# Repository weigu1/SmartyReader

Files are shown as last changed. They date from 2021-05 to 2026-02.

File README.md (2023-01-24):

# SmartyReader: Reading encrypted Luxembourgish smartmeter data

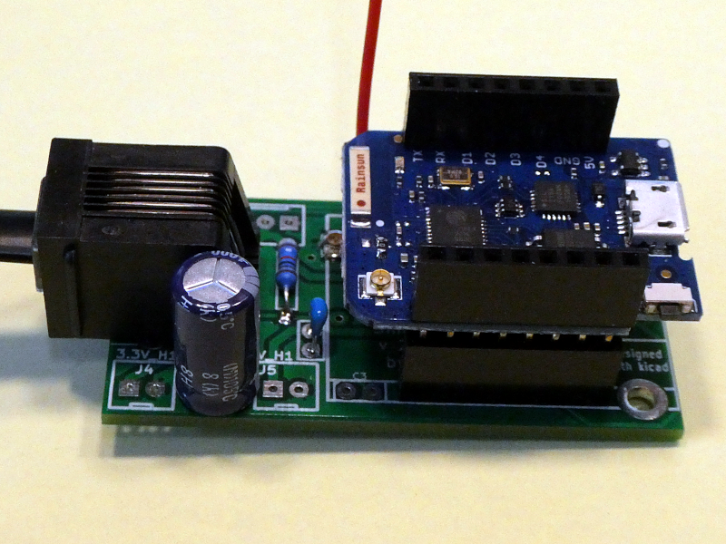
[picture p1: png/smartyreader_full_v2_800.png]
smartyreader


## All infos on: <http://weigu.lu/microcontroller/smartyReader/index.html>

## Some infos

Because of the EU Energy Efficiency Directive from 2012 the gas and electricity Distribution System Operators (DSO) in Luxembourg replaced there gas and energy meters with smartmeters (named smarty :() from Sagemcom (T210-D).

As it seems the same smartmeters are deployed in Sweden, parts of Austria and the Netherlands.

These smartmeters have a user port that delivers 10 second data (RJ12 connector under the green lid). The P1 data output communication protocol and format is specified in the  [Dutch Smart Meter Requirements v5.0.2 ](https://smarty.creos.net/wp-content/uploads/DutchSmartMeterRequirements.pdf). The solution deployed in Luxembourg includes an additional security layer standard that is conform to the IDIS package 2.0 requirement. The encryption layer is based on DLMS security suite 0 algorithm: AES128-GCM. More information can be found in this [document](https://smarty.creos.net/wp-content/uploads/P1PortSpecification.pdf).

The Smartyreader is a simple board designed with KiCAD and decrypting the smartmeter data with an ESP8266 (Lolin D1 mini pro). The data is then published over MQTT via WiFi or Ethernet. A new version allows also to use LoRa or LoRaWAN.

For infos from the newest software look here: <https://github.com/weigu1/SmartyReader/tree/main/Arduino/SmartyReader_P1_WiFi_Ethernet>.

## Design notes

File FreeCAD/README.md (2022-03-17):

# SmartyReader housing

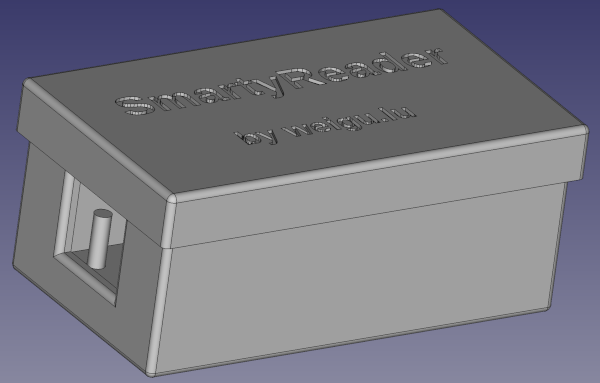
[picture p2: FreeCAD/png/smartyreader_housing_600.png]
smartyreader


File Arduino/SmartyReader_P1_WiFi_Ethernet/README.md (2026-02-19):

# SmartyReader: Reading encrypted Luxembourgish smartmeter data

## The Software (MQTT via WiFi or Ethernet) to use with an ESP8266

### Install Arduino and the libraries needed:

+ Good to know:<br>
1. To program the D1 mini pro, remove it from the socket!
2. If you buy today D1 mini pro's you get often cloned boards. Select in Arduino IDE D1 mini (clone)!
3. The Ethernet version needs a RESET (button) after being connected to the Smartmeter to start.

The newer software uses my ESPToolbox lib, that is included in the sketch folder.

First install the newest Arduino IDE. To use our ESP8266 LOLIN/WEMOS we add this line ```http://arduino.esp8266.com/stable/package_esp8266com_index.json``` to ```File-Preferences-Additional_Boards_Manager_URLs:```.

Then we install support for ESP8266 boards by going to `Tools > Board: > Boards Manager...`. In the Manager window we type **esp8266** in the search field, select esp8266 and click on `install`. Close the window and choose the board `LOLIN/WEMOS D1 mini Pro` under `Tools > Board:` (you have to scroll).

We need a the following libraries:

+ `Crypto` (Rhys Wheatherley)
+ `PubSubClient`  (by Nick O'Leary)
+ `ArduinoJson` (Benoit Blanchon)
+ `circular Buffer` (AgileWare, Roberto Lo Giacco)
+ `BME280` (Tyler Glenn); only if you use a BME280! 

To install them go to `Tools > Manage Libraries...`. Type in the search field the name of the library, choose it and install it. Sometimes you have to scroll down to find the right lib.

If you want to use the config `config.h` file uncomment `SECRETS`. If you want to use the a secret config file, create a folder named `Secrets` in the sketchbook libraries folder (`sketchbook/libraries`). Now copy the content of `config.h` to a file named `secrets.h`. Place this file in the `Secrets` folder.

### Version 1.7

Since january first 2025 the costs for the electricity net in Luxembourg include, in addition to the fixed costs, a new calculation that takes power classes into account (3&#8239;kW, 7&#8239;kW, 12&#8239;kW ...). You are assigned to such a power class and have to pay more if your consumption exceeds it.

The new software version calculates this data if required. In addition, thanks to Markus Schoellauf, an MQTT discovery method for Home Assistant has been integrated. We also now have a last will :) thanks to Jean-Marie Quintus.

These two changes have not yet been thoroughly tested. If you find an error, please let me know.

### Version 1.6

This new version got a lot of changes:

A new config file (`config.h`) contains all the things that must be changed or are safe to change.

In this new version I changed the publishing format. Every item (DSMR and new calculated values) is published under its own topic. No more JSON strings but directly the values (easier to handle wit home automation software). In `config.h` (or secrets.h) you can decide with 'y/n' if you want to publish the parameter or not.

To be better able to write simpler rules I added calculated values described below.

#### Define lines in the main program

The main program (.ino) contains still the define lines that can be commented or uncommented. Removing the two slashes (`//`) means the line is active (uncommented). To make a line inactive, add two slashes at the beginning of the line. 

+ `USE_SECRETS` will use a file named `secrets.h` instead of the `config.h` file. This file must contain the same things than the config file (`config.h`) but must be located in the sketchbook `libraries` folder of your Arduino IDE  in a folder named `Secrets`. This makes it easier to test and distribute the software without sharing the WiFi password and so compromising security.

+ `OTA` will enable the Over The Air update possibility (security risk!). This comes handy to reprogram your SmartyReader while connected to the Smartmeter. In the config file you can change the name you see in the port menu of the Arduino IDE, and the password. To use a minimum of security we calculate an MD5 hash of our password, so that the password is not contained in cleartext in the Flash of the microcontroller. You can calculate MD5 hashes from a password with online tools.

+ `MQTTPASSWORD` enables an MQTT connection protected with a password (recommended!!). Check the config file to set the password.

+ `STATIC` can be used if you want a static IP instead of a changing IP. The IP address is set in the config file.

+ `ETHERNET` if you don't want to use WiFi. For this you must add a Funduino (W5100) breakout board to your SmartyReader.

+ `BME280_I2C` to add a temperature sensor to your SmartyReader. The data is published under the topics "bme280_temperature_C", "bme280_humidity_%" and "bme280_pressure_hPa". Don't forget to solder two 1.8k resistors (0805, R5 and R6) to your board! 

+ `GET_NTP_TIME` to add the the real time (from an NTP Server).

+ `PUBLISH_COOKED` is used to get only one JSON string with all the calculated values. In this new version every item (DSMR and calculated) is published under its own topic. No more JSON strings but directly the values (easier to handle wit home automation software). In `config.h` (or secrets.h) you can decide with 'y/n' if you want to publish the parameter or not.

+ `OLD_HARDWARE` must be used for boards before V2.0, because here the serial signal is inverted with hardware (transistor) instead of software.

+ `FUNDUINO_W5100` for Ethernet boards before V2.2 if using Ethernet.

#### The config file (`config.h`). 

Mandatory things to change are your WiFi credentials, your Smartmeter key (get it from your electricity distribution system operator) and the IP address of your MQTT server (e.g. Raspberry Pi).

The following things can be changed:

+ `PUBLISH_TIME`: in ms. The minimum is 10 seconds and it makes sense to use a multiple of this. A good value is 60000, to get data once a minute.

+ `SAMPLE_TIME_MIN`: The mean value of the power and the min and max values are calculated over this time. If we set this time to 10 min, 60 values are used to calculate the mean power.

+ `MQTT`: The client ID must be unique, so change it if you use more than one SmartyReader!! Choose your own topic. User and Password is only needed if you uncommented `MQTTPASSWORD`. Default port is 1883.

+ `WiFi`: With an MDNS name you can access your SmartyReader with the name .local instead the IP. With a hostname it is easier to find your SmartyReader IP with the router or nmap. If you use UDP to debug (look below) you can change here the IP address of your client and the port. You can also change the NTP server and your time zone.

+ `OTA`: If you use OTA (uncomment `OTA` in the main file (.ino)). 

+ `STATIC`: If you use a static IP address (uncomment `STATIC` in the main file (.ino)). 

+ `ETHERNET`: If you use an ethernet breakout board (uncomment `ETHERNET` in the main file (.ino)) you can change the MAC to get a unique address.

+ `AUTH_DATA`: In Austria this data is not hard coded, so here you can change it (17 byte!).

+ `PUBLISH`: In the two following tables you can define if a parameter is published or not. To prevent publishing, repalce the lowercase 'y' with another char e.g. 'n'.

#### Debugging

Debugging options are enabled in the main file (.ino) in the `setup()` function. By default all 3 logging options are enabled (true). 

+ `Tb.set_led_log(true)` uses the built-in LED for debugging (different blink patterns).
+ `Tb.set_serial_log(true,1)` uses the second (1 = Serial1) or third (ESP32, (2 = Serial2)) hardware serial interface to debug. The first (Serial or Serial0) is used by the Smartmeter and can't be used to debug. You can connect a Serial to USB adapter to this hardware interface pins (D4 (Tx1) and GND for ESP8266) and use a terminal program to log the stream.

+ `Tb.set_udp_log(true, UDP_LOG_PC_IP, UDP_LOG_PORT)` is the coolest option. Use a computer to get the logging over an UDP stream. On a Linux system (e.g. Raspberry Pi) you can use the `netcat` command (nc) in a terminal: `nc -kulw 0 6666`. The port and IP address are set in `config.h` under "WiFi and network settings".

To add your own debug strings use `Tb.log("mytext")`or `Tb.log_ln("mytext")`.

#### The calculated values

##### The smartmeter is a balancing counter

Smartmeter are balancing counter (german: saldierender Zähler). This can lead to confusion when looking at the power values from your Smartmeter.

###### A little example:

If your solar plant is giving you 6&#8239;kW on 3 phases (L1, L2, L3), you get 2&#8239;kW per phase. If you are charging your EV at the same time with 4&#8239;kW on phase L1, the SmartyReader will show you the following values:

`act_pwr_imported_p_plus` (1.7.0) = 2&#8239;kW

`act_pwr_exported_p_minus` (2.7.0) = 4&#8239;kW

`act_pwr_imp_p_plus_l1` (21.7.0) = 2&#8239;kW

`act_pwr_imp_p_plus_l2` (41.7.0) = 0&#8239;kW

`act_pwr_imp_p_plus_l3` (61.7.0) = 0&#8239;kW

`act_pwr_exp_p_minus_l1` (22.7.0) = 0&#8239;kW

`act_pwr_exp_p_minus_l2` (42.7.0) = 2&#8239;kW

`act_pwr_exp_p_minus_l3` (62.7.0) = 2&#8239;kW

But if we calculate the power from the energy values we see that in fact there is no energy imported and 2&#8239;kW are exported.

To calculate the power from energy we need two energy values (E1 and E2) and the time between these two values (&#916;t): P = (E2-E1)/&#916;t.

Another solution is to calculate the difference between `act_pwr_imported_p_plus` (1.7.0) and `act_pwr_exported_p_minus` (2.7.0). 
P = power exported - power imported. If this difference is positive we get an excess of solar power, and energy is only exported (no energy is imported). If it is negative (contrained to zero in software), we consume energy.

###### SmartyReader calculated values

To get a better overview, the new software is calculating the solar excess power, and the power from energy.

It calculates also the mean power over the last x minutes (x changeable in `config.h`), as the min and max values over the last x minutes. For this all available values (10 second values) are used. With these values it is easier to write rules for days with fast changing solar radiation.

## More infos on: <http://weigu.lu/microcontroller/smartyReader/index.html>

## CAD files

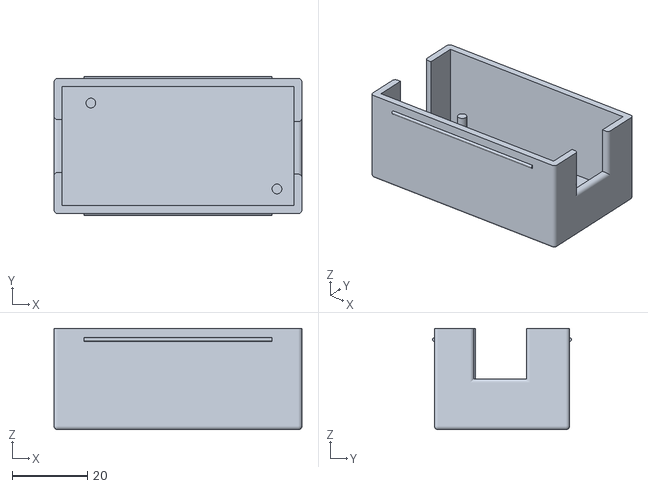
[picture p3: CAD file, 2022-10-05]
FreeCAD/SmartyReader_P1_WiFi-Case.stl
66.0 x 37.0 x 27.0

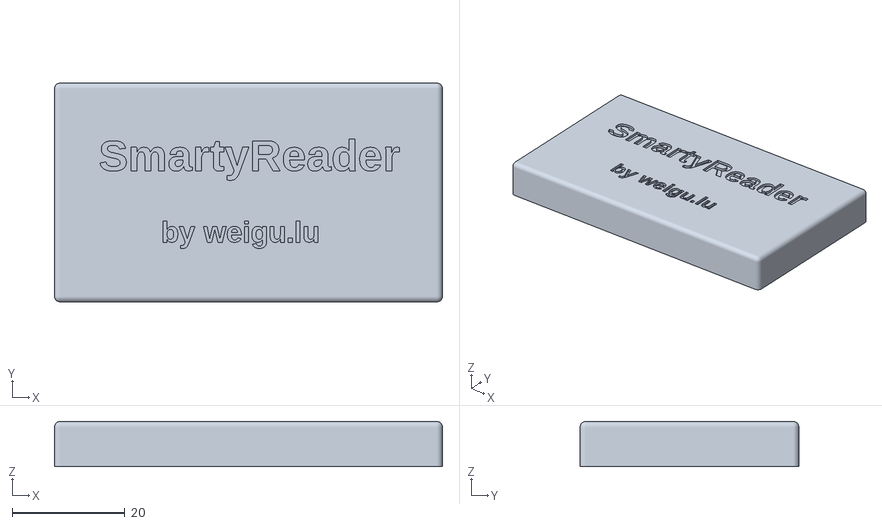
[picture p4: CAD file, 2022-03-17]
FreeCAD/SmartyReader_P1_WiFi_Lid.stl
68.8 x 38.8 x 8.00

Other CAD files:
FreeCAD/SmartyReader_P1_WiFi.FCStd

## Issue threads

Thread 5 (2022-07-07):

ESP32-POE-ISO sends mqtt messages in uneven time intervals

u20p17, 2022-07-07:
Hi,
I am using a ESP32-POE-ISO which get powered by POE and is located near the smartmeter (Sagemcom T210-D-r). I already got the encryption key and modified your 1.6 beta code in order that the ethernet was working (and the general MQTT/network... settings in the config file.
After flashing an connecting I get some data via MQTT. As a test I set the publish time to 10s. As you can see it is working like expected and suddenly it stops for several minutes (more than 70min!) and after that it is working again for some mqtt messages and then it stops again for a long time.

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

What could be the problem?

Furthermore, lot of the channels are just 0. Is this a problem of my smartmeter ( maybe the energy company has to activate them?) or might it be related to the code?

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

Here my updated code:
[SmartyReader_v1_6_beta.zip](https://github.com/weigu1/SmartyReader/files/9060960/SmartyReader_v1_6_beta.zip)

Thanks in advance!

weigu1, 2022-07-08:
Hi there,

First the simple question :) The zeros are related  to your energy company. In Luxembourg they sent in the beginning 700 bytes with the currents per phase, then after an update only 500 bytes without the currents. After some clients complained they now sent also the power per phase (1100 byte). So ask your company for more data.

I had the same problems in the beginning of the year with ESP32. They worked sometimes one week without complaint and then stopped for some hours without logging errors. I had no time to dig deeper and replaced them with ESP8266. We also had other problems with ESP32 that could be solved by downgrading on a core version before 3.0. So perhaps you could try this (in Boards manager you can choose the version).
Another problem could be a not enough or stable power supply (add a big capacitor).

Sorry, but for the moment I can't look into this more deeply.

Greetings
Guy

u20p17, 2022-07-13:
Hi,
Thanks for the answer. I will contact the energy company and ask if they can also activate the full data output of the smartmeter.

Do you have a complete set that you could sell me? Would save me some work for soldering the platine ;)

Thanks!

weigu1, 2022-07-14:
Hi,
For a kit, please send me your address to weigu@weigu.lu.
Greetings

Closed 2022-07-16.

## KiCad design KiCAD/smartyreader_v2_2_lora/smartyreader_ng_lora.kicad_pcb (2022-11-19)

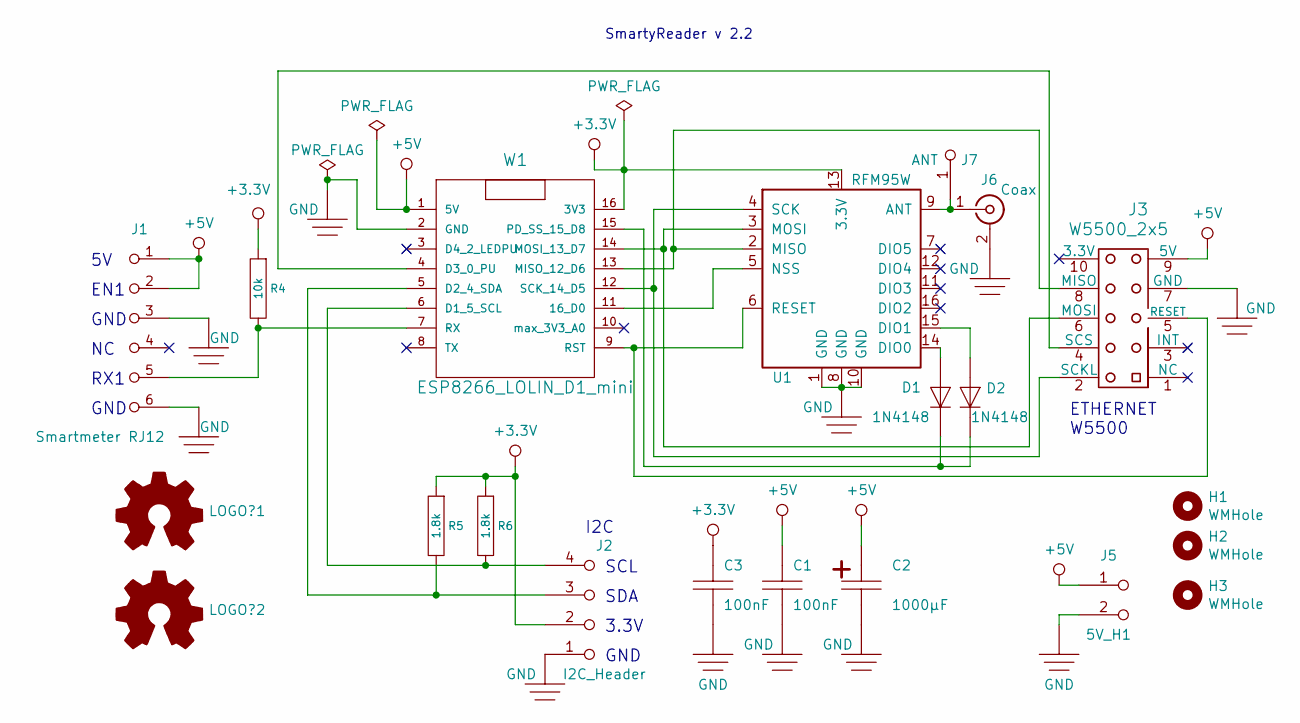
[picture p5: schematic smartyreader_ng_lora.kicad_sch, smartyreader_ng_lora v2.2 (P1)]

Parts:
C1, C3: 100nF; WC1
C2: 1000µF; WC1V
D1, D2: 1N4148; W0805
H1, H2, H3: WMHole; WPin_3mm
J1: Smartmeter RJ12; WRJ12
J2: I2C_Header; WSIL4_SL
J3: W5500_2x5; WW5500
J5: 5V_H1; WSIL2_SL
J6: Coax; U.FL_Molex_MCRF_73412-0110_Vertical
J7: ANT; WPin_1mm
LOGO?1, LOGO?2: Open_Hardware_Logo; OSHW-Logo_5.7x6mm_SilkScreen
R4: 10k; WR4
R5, R6: 1.8k; W0805
U1: RFM95W; HOPERF_RFM9XW_SMD
W1: ESP8266_LOLIN_D1_mini; WWEMOSD1

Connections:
+3.3V: C3.1, J2.2 (12), R4.1, R5.1, R6.1, U1.13 (3.3V), W1.16 (3V3)
+5V: C1.1, C2.1, J1.1, J1.2, J3.9 (5V), J5.1 (11), W1.1 (5V)
unnamed: D1.1 (A), U1.14 (DIO0)
unnamed: D1.2 (K), D2.2 (K), W1.15 (PD_SS_15_D8)
unnamed: D2.1 (A), U1.15 (DIO1)
unnamed: J1.5, R4.2, W1.7 (RX)
unnamed: J2.3 (13), R5.2, W1.5 (D2_4_SDA)
unnamed: J2.4 (14), R6.2, W1.6 (D1_5_SCL)
unnamed: J3.2 (SCKL), U1.4 (SCK), W1.12 (SCK_14_D5)
unnamed: J3.4 (SCS), W1.4 (D3_0_PU)
unnamed: J3.5 (RESET), U1.6 (RESET), W1.9 (RST)
unnamed: J3.6 (MOSI), U1.3 (MOSI), W1.14 (MOSI_13_D7)
unnamed: J3.8 (MISO), U1.2 (MISO), W1.13 (MISO_12_D6)
unnamed: J6.1 (In), J7.1 (11), U1.9 (ANT)
unnamed: U1.5 (NSS), W1.11 (16_D0)
~: C1.2, C2.2, C3.2, J1.3, J1.6, J2.1 (11), J3.7 (GND), J5.2 (12), J6.2 (Ext), U1.1 (GND), U1.8 (GND), U1.10 (GND), W1.2 (GND)

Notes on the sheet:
EN1
SCL
GND
SDA
SmartyReader v 2.2
ETHERNET W5500
3.3V
I2C
RX1

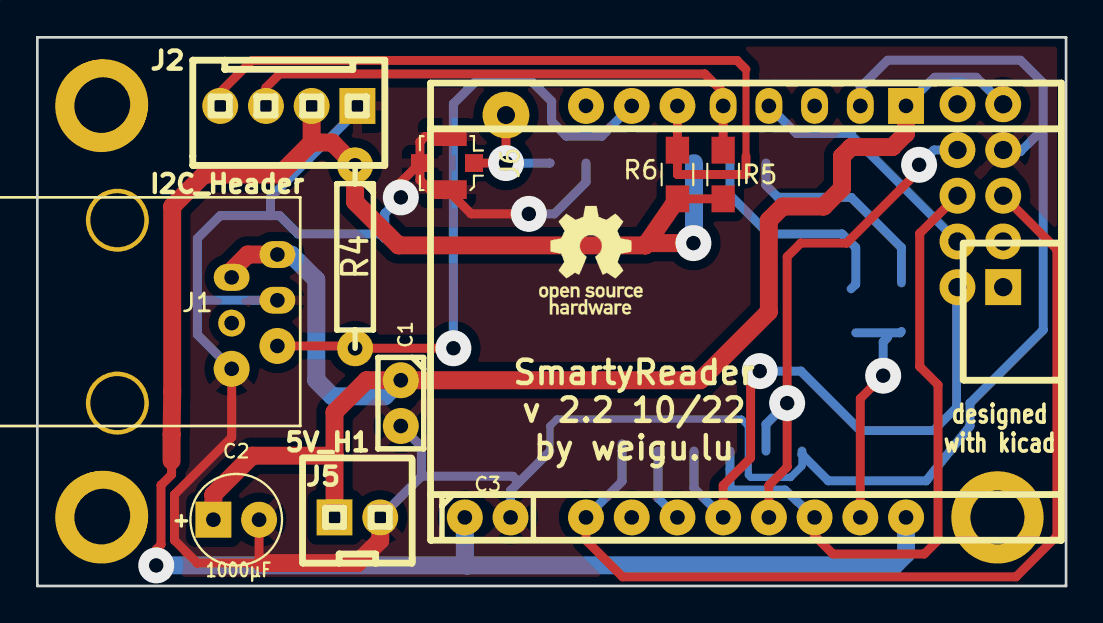
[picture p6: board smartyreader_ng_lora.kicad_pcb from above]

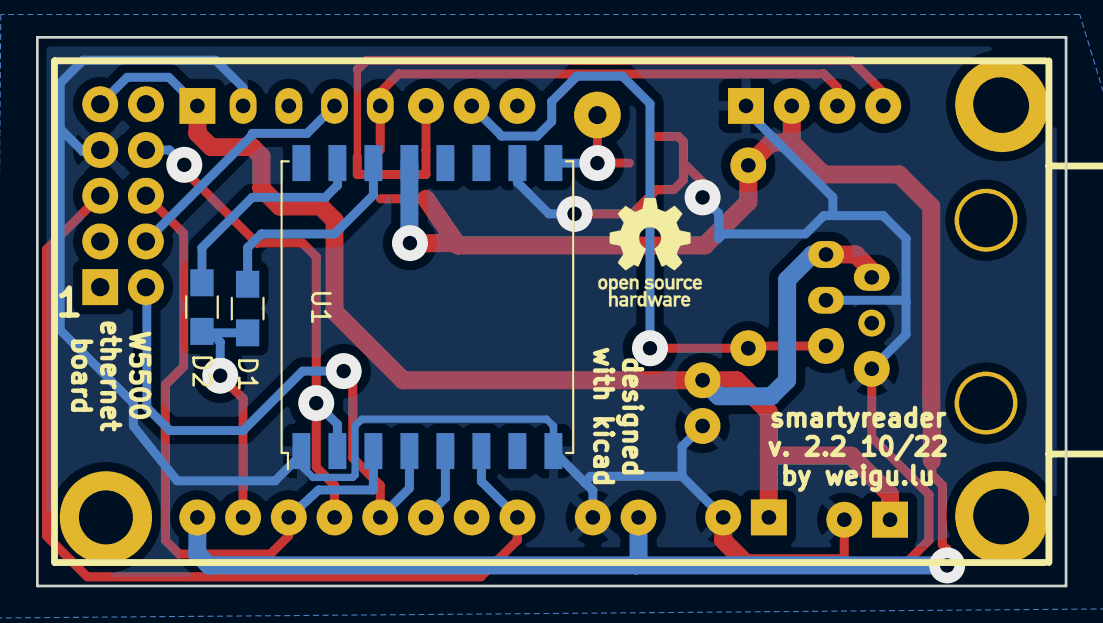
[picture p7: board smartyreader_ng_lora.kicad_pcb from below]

Board: 2 copper layers, 57.1 x 30.5 mm, 21 parts (5 on the bottom side), 16 nets.

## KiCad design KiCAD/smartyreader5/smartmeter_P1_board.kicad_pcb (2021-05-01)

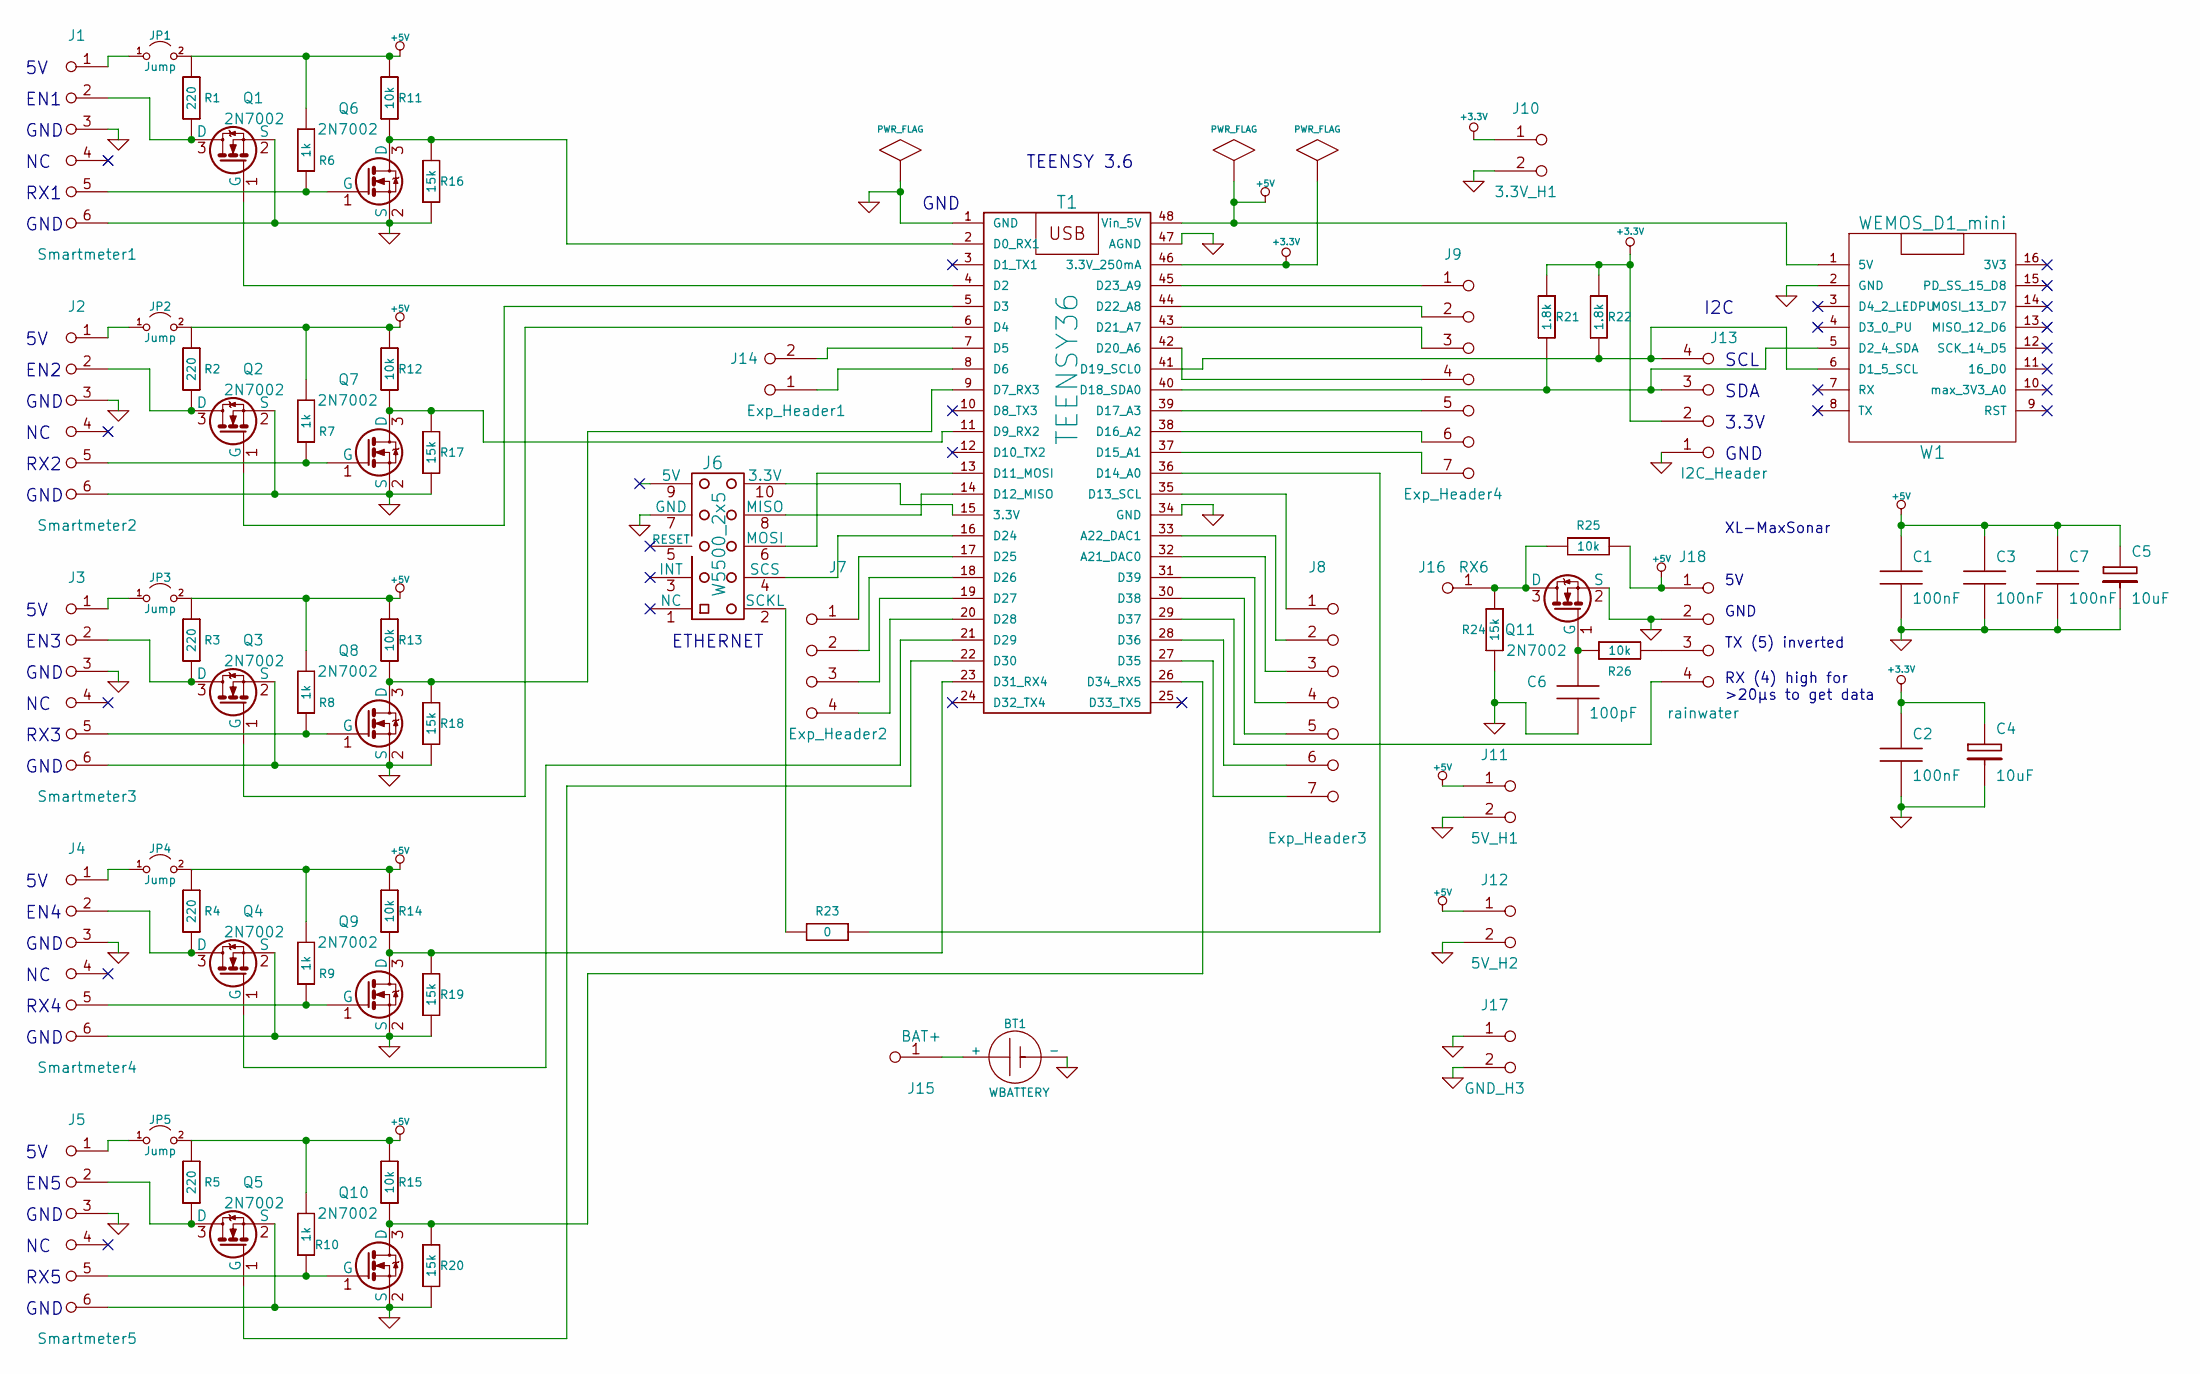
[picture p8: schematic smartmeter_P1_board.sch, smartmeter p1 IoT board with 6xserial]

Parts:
BT1: WBATTERY; WBAT
C1, C2, C3, C7: 100nF; W0805
C4, C5: 10uF; W1206
C6: 100pF; W0805
J1: Smartmeter1; WRJ12
J2: Smartmeter2; WRJ12
J3: Smartmeter3; WRJ12
J4: Smartmeter4; WRJ12
J5: Smartmeter5; WRJ12
J6: W5500_2x5; WW5500
J7: Exp_Header2; WSIL4_SL
J8: Exp_Header3; WSIL8_SL
J9: Exp_Header4; WSIL7_SL
J10: 3.3V_H1; WSIL2_SL
J11: 5V_H1; WSIL2_SL
J12: 5V_H2; WSIL2_SL
J13: I2C_Header; WSIL4_SL
J14: Exp_Header1; WSIL2_SL
J15: BAT+; WSIL1
J16: RX6; WSIL1
J17: GND_H3; WSIL2
J18: rainwater; WSIL4
JP1, JP2, JP3, JP4, JP5: Jump; WSIL2
Q1, Q2, Q3, Q4, Q5, Q6, Q7, Q8, Q9, Q10, Q11: 2N7002; SOT-23
R1, R2, R3, R4, R5: 220; W0805
R6, R7, R8, R9, R10: 1k; W0805
R11, R12, R13, R14, R15, R25, R26: 10k; W0805
R16, R17, R18, R19, R20, R24: 15k; W0805
R21, R22: 1.8k; W0805
R23: 0; W1206
T1: TEENSY36; WTEENSY36
W1: WEMOS_D1_mini; WWEMOSD1

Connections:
+3.3V: C2.1, C4.1, J10.1 (11), J13.2 (12), R21.1, R22.1, T1.46 (3.3V_250mA)
+5V: C1.1, C3.1, C5.1, C7.1, J11.1 (11), J12.1 (11), J18.1 (11), JP1.2, JP2.2, JP3.2, JP4.2, JP5.2, R1.1, R2.1, R3.1, R4.1, R5.1, R6.1, R7.1, R8.1, R9.1, R10.1, R11.1, R12.1, R13.1, R14.1, R15.1, R25.1, T1.48 (Vin_5V), W1.1 (5V)
GND: BT1.2 (-), C1.2, C2.2, C3.2, C4.2, C5.2, C6.2, C7.2, J1.3, J1.6, J2.3, J2.6, J3.3, J3.6, J4.3, J4.6, J5.3, J5.6, J6.7 (GND), J10.2 (12), J11.2 (12), J12.2 (12), J13.1 (11), J17.1 (11), J17.2 (12), J18.2 (12), Q1.2 (S), Q2.2 (S), Q3.2 (S), Q4.2 (S), Q5.2 (S), Q6.2 (S), Q7.2 (S), Q8.2 (S), Q9.2 (S), Q10.2 (S), Q11.2 (S), R16.2, R17.2, R18.2, R19.2, R20.2, R24.2, T1.1 (GND), T1.34 (GND), T1.47 (AGND), W1.2 (GND)
unnamed: BT1.1 (+), J15.1
unnamed: C6.1, Q11.1 (G), R26.2
unnamed: J1.1, JP1.1
unnamed: J1.2, Q1.3 (D), R1.2
unnamed: J1.5, Q6.1 (G), R6.2
unnamed: J2.1, JP2.1
unnamed: J2.2, Q2.3 (D), R2.2
unnamed: J2.5, Q7.1 (G), R7.2
unnamed: J3.1, JP3.1
unnamed: J3.2, Q3.3 (D), R3.2
unnamed: J3.5, Q8.1 (G), R8.2
unnamed: J4.1, JP4.1
unnamed: J4.2, Q4.3 (D), R4.2
unnamed: J4.5, Q9.1 (G), R9.2
unnamed: J5.1, JP5.1
unnamed: J5.2, Q5.3 (D), R5.2
unnamed: J5.5, Q10.1 (G), R10.2
unnamed: J6.2 (SCKL), R23.2
unnamed: J6.4 (SCS), T1.16 (D24)
unnamed: J6.6 (MOSI), T1.13 (D11_MOSI)
unnamed: J6.8 (MISO), T1.14 (D12_MISO)
unnamed: J6.10 (3.3V), T1.15 (3.3V)
unnamed: J7.1 (11), T1.17 (D25)
unnamed: J7.2 (12), T1.18 (D26)
unnamed: J7.3 (13), T1.19 (D27)
unnamed: J7.4 (14), T1.20 (D28)
unnamed: J8.1 (11), T1.35 (D13_SCL)
unnamed: J8.2 (12), T1.33 (A22_DAC1)
unnamed: J8.3 (13), T1.32 (A21_DAC0)
unnamed: J8.4 (14), T1.31 (D39)
unnamed: J8.5 (15), T1.30 (D38)
unnamed: J8.6 (16), T1.28 (D36)
unnamed: J8.7 (17), T1.27 (D35)
unnamed: J9.1 (11), T1.45 (D23_A9)
unnamed: J9.2 (12), T1.44 (D22_A8)
unnamed: J9.3 (13), T1.43 (D21_A7)
unnamed: J9.4 (14), T1.42 (D20_A6)
unnamed: J9.5 (15), T1.39 (D17_A3)
unnamed: J9.6 (16), T1.38 (D16_A2)
unnamed: J9.7 (17), T1.37 (D15_A1)
unnamed: J13.3 (13), R21.2, T1.40 (D18_SDA0), W1.5 (D2_4_SDA)
unnamed: J13.4 (14), R22.2, T1.41 (D19_SCL0), W1.6 (D1_5_SCL)
unnamed: J14.1 (11), T1.8 (D6)
unnamed: J14.2 (12), T1.7 (D5)
unnamed: J16.1, Q11.3 (D), R24.1, R25.2
unnamed: J18.3 (13), R26.1
unnamed: J18.4 (14), T1.29 (D37)
unnamed: Q1.1 (G), T1.4 (D2)
unnamed: Q2.1 (G), T1.5 (D3)
unnamed: Q3.1 (G), T1.6 (D4)
unnamed: Q4.1 (G), T1.21 (D29)
unnamed: Q5.1 (G), T1.22 (D30)
unnamed: Q6.3 (D), R11.2, R16.1, T1.2 (D0_RX1)
unnamed: Q7.3 (D), R12.2, R17.1, T1.11 (D9_RX2)
unnamed: Q8.3 (D), R13.2, R18.1, T1.9 (D7_RX3)
unnamed: Q9.3 (D), R14.2, R19.1, T1.23 (D31_RX4)
unnamed: Q10.3 (D), R15.2, R20.1, T1.26 (D34_RX5)
unnamed: R23.1, T1.36 (D14_A0)

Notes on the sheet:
GND
TEENSY 3.6
RX1
I2C
ETHERNET
EN1
RX2
EN2
RX3
EN3
RX4
EN4
RX5
EN5
3.3V
SDA
SCL
RX (4) high for >20µs to get data
TX (5) inverted
XL-MaxSonar

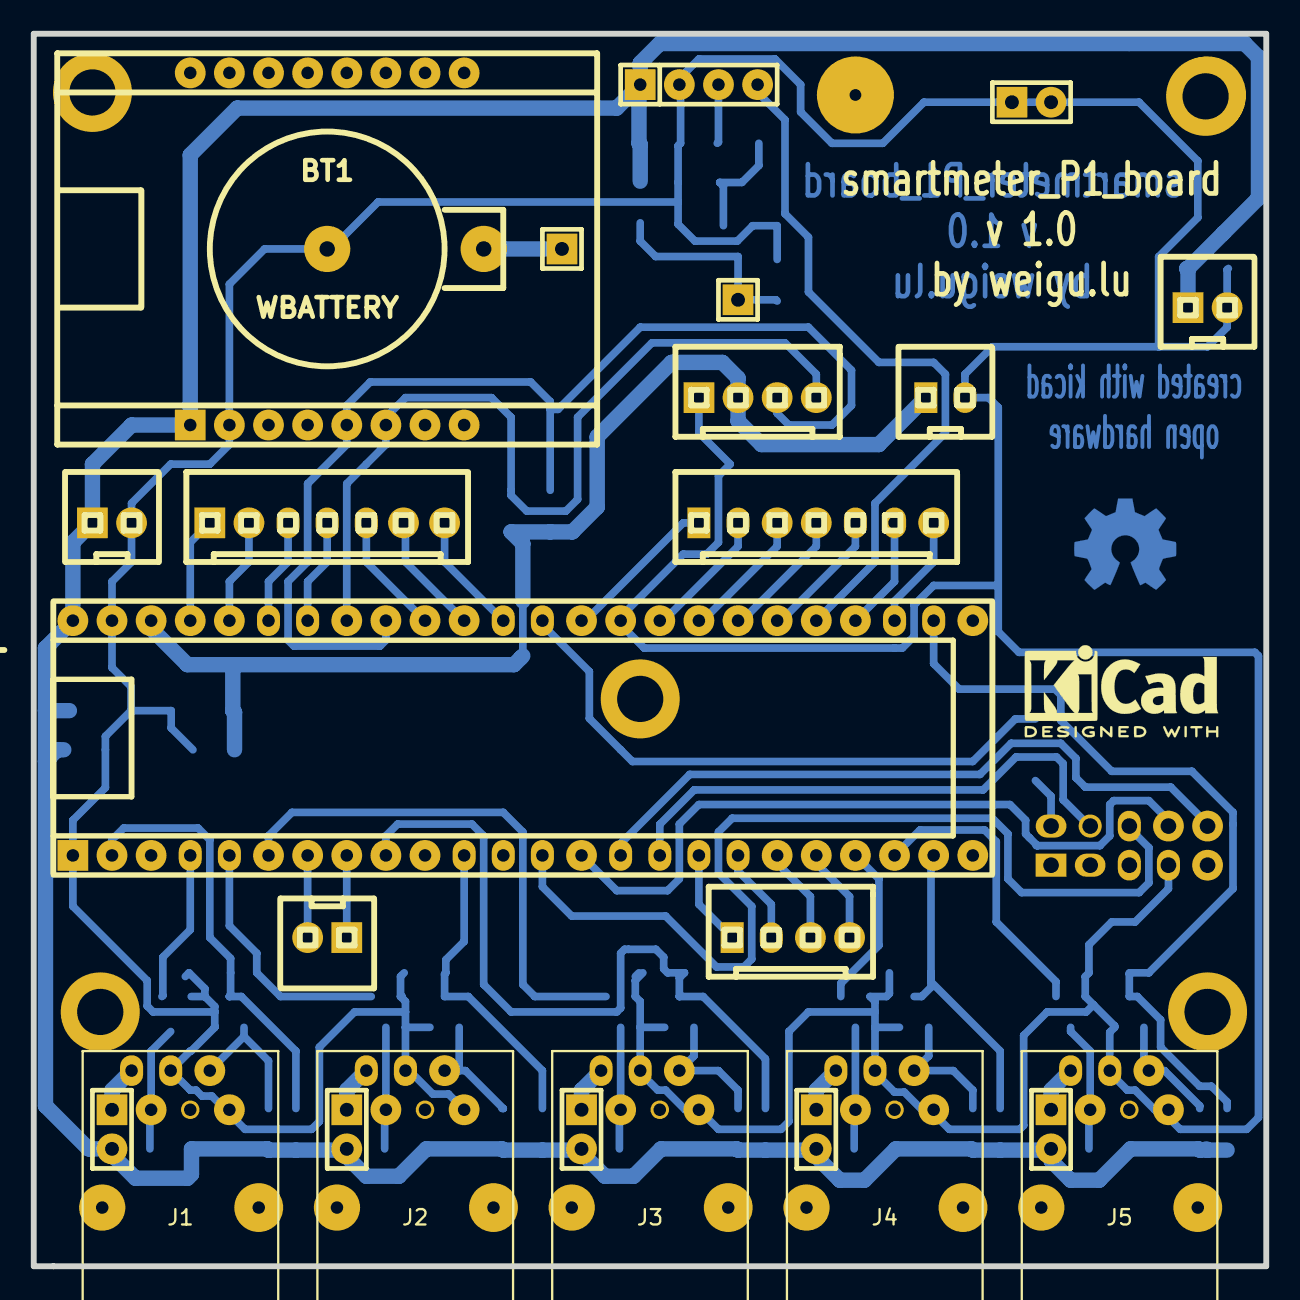
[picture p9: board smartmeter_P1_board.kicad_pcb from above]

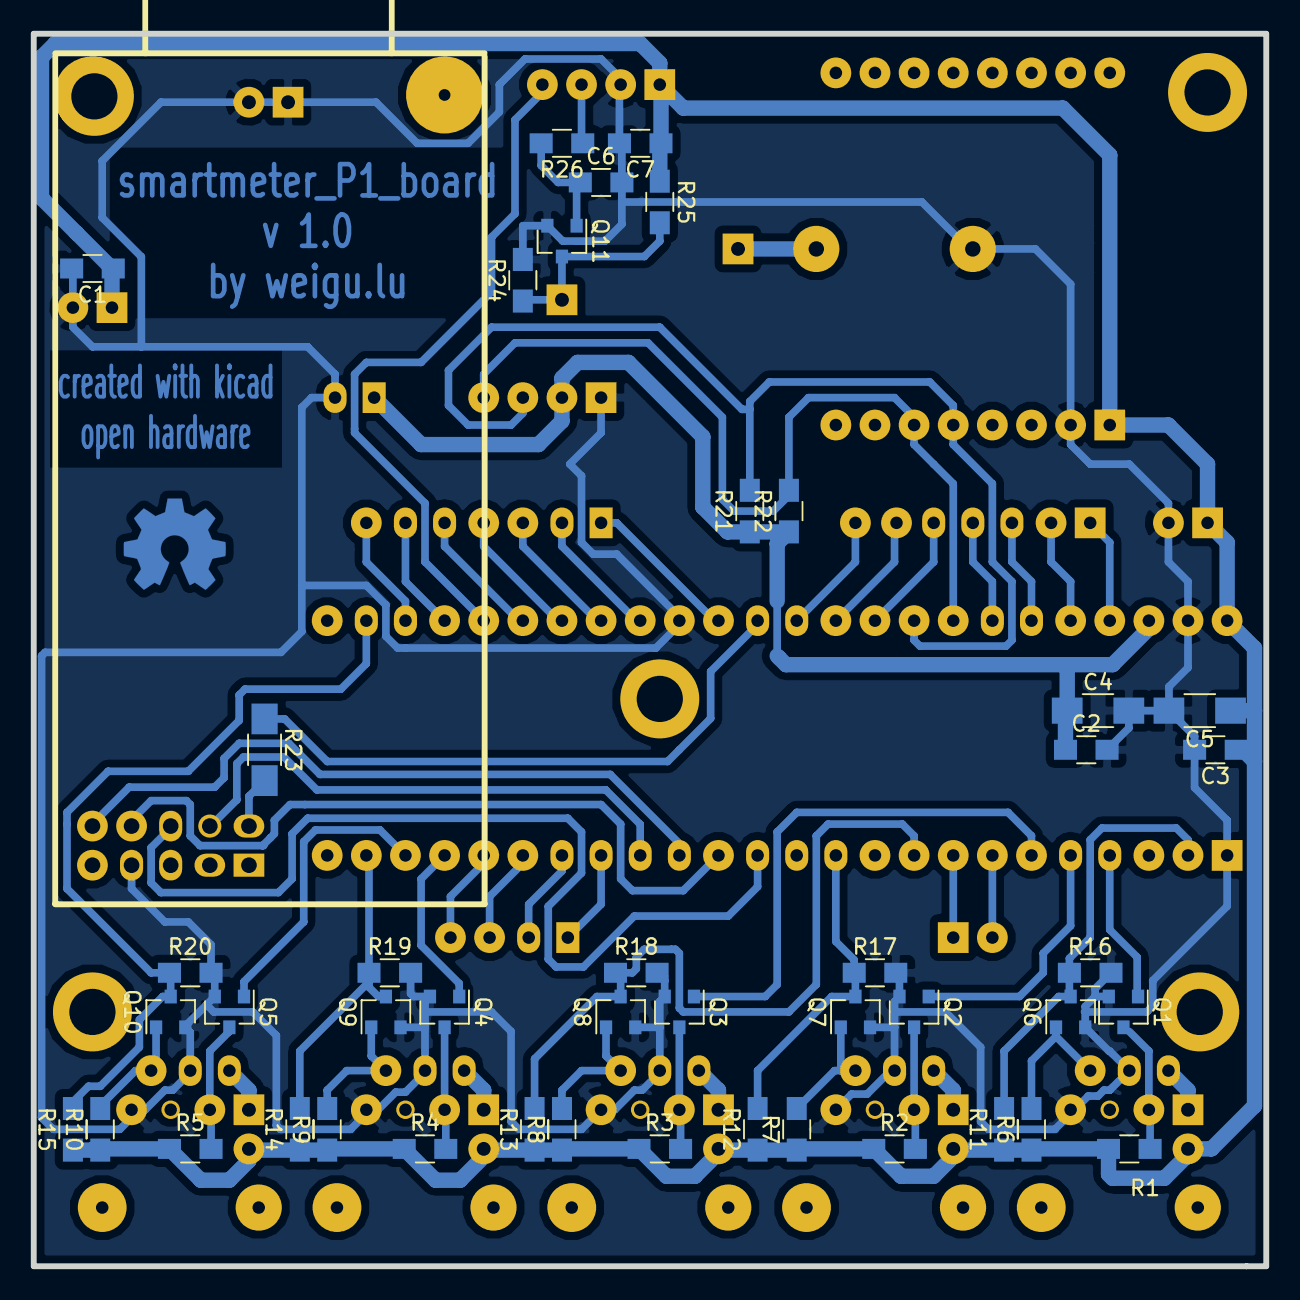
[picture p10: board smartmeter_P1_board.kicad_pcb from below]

Board: 2 copper layers, 80.0 x 80.0 mm, 75 parts (45 on the bottom side), 61 nets.

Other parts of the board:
AD1, AD1#2, AD1#3, AD1#4, AD1#5: C1; WPin_3mm

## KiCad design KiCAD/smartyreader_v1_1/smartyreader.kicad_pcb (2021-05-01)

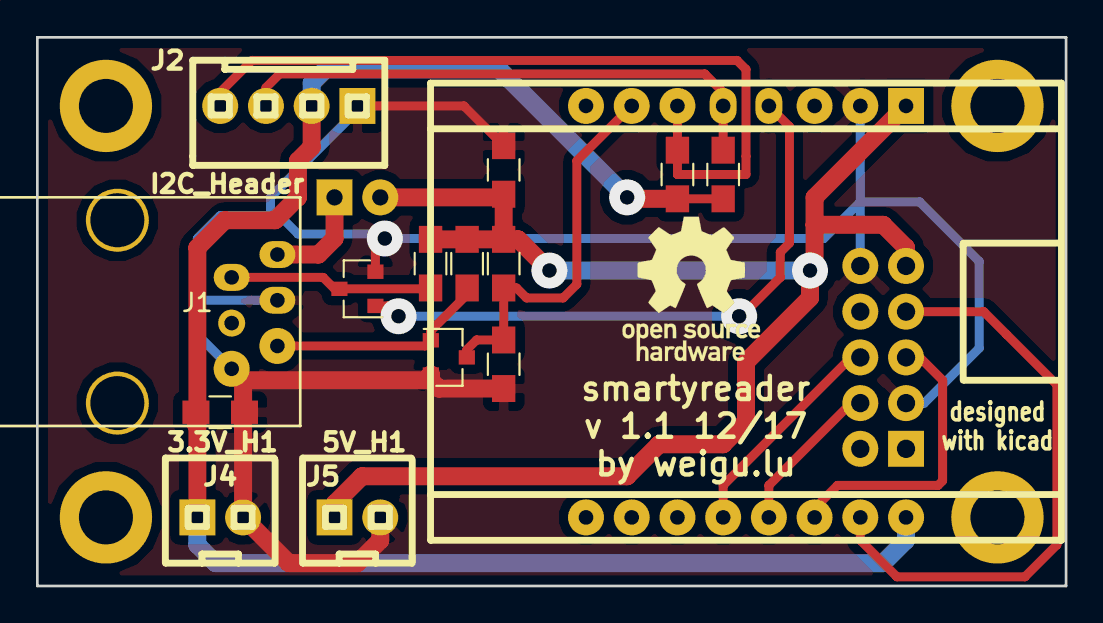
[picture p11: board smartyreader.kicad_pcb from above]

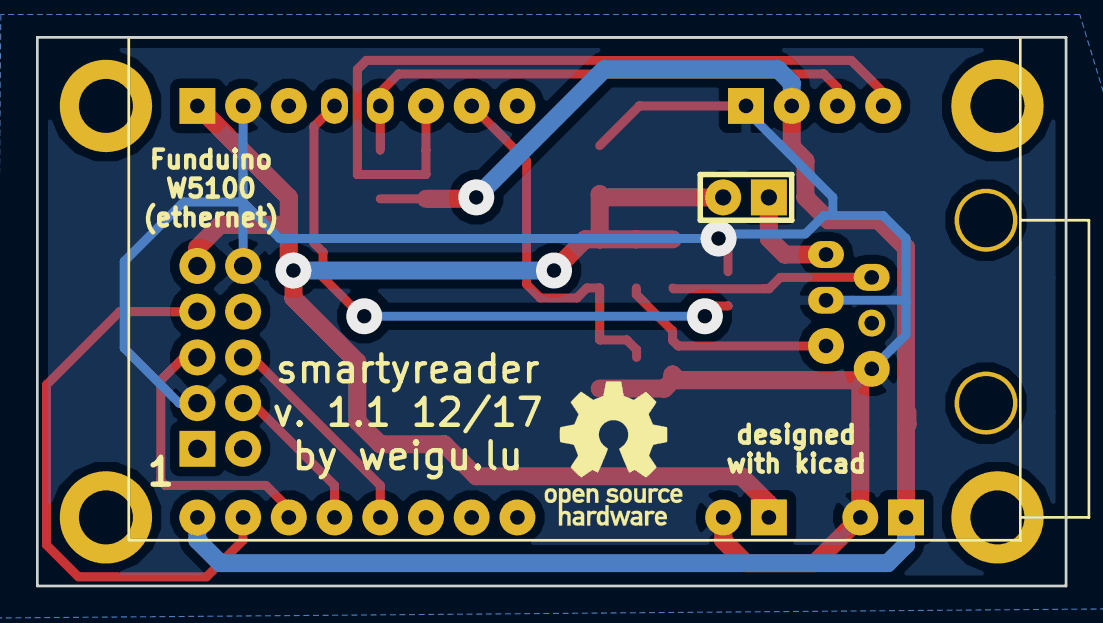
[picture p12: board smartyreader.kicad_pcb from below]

Board: 2 copper layers, 57.1 x 30.5 mm, 21 parts (2 on the bottom side), 14 nets.

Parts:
AD1, AD1#2, AD1#3, AD1#4: C1; WPin_3mm
C1, C2: 100n; W0805
J1: RJ12; WRJ12
J2: I2C_Header; WSIL4_SL
J3: W5100_2x5; WW5100
J4: 3.3V_H1; WSIL2_SL
J5: 5V_H1; WSIL2_SL
JP1: Jump; WSIL2
Q1, Q2: 2N7002; SOT-23
R1: 220; W0805
R2: 1k; W0805
R3: 10k; W0805
R4: 15k; W0805
R5, R6: 1.8k; W0805
W1: WEMOS_D1_mini; WWEMOSD1

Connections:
+3.3V: C2.1, J2.2, J4.1, R5.1, R6.1, W1.16
+5V: C1.1, J3.9, J5.1, JP1.2, R1.1, R2.1, R3.1, W1.1
GND: C1.2, C2.2, J1.3, J1.6, J2.1, J3.3, J3.10, J4.2, J5.2, Q1.2, Q2.2, R4.2, W1.2
unnamed: J1.1, JP1.1
unnamed: J1.2, Q1.3, R1.2
unnamed: J1.5, Q2.1, R2.2
unnamed: J2.3, R5.2, W1.5
unnamed: J2.4, R6.2, W1.6
unnamed: J3.4, W1.13
unnamed: J3.5, W1.14
unnamed: J3.6, W1.12
unnamed: J3.7, W1.15
unnamed: Q1.1, W1.4
unnamed: Q2.3, R3.2, R4.1, W1.7

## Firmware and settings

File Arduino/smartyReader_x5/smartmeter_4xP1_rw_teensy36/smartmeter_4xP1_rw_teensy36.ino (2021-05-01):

/*
 * smartmeter_4xp1_rw_teensy36.ino
 * read 4 (5) P1 ports from smartmeters
 * and rainwater sensor () and publish with MQTT
 *
 * teensy 3.6 with teensyduino 1.37
 *
 * weigu.lu
 *
 * change RX buffer to 1024 for smartmeter n (#define SERIALn_RX_BUFFER_SIZE)
 * in arduino-1.8.0/hardware/teensy/avr/cores/teensy3/serialn.c
 *
 * (changed message size to 256 in
 * /Arduino/libraries/pubsubclient-master/src/PubSubClient.h)
 * 
 * v 11/4/18
*/

#include <Ethernet.h>
#include <PubSubClient.h>
#include <SPI.h>
#include <SD.h>
#include <TimeLib.h>
#include <Crypto.h>
#include <AES.h>
#include <GCM.h>
#include <string.h>
//#include <Wire.h> // for DS3132

#define MQTT_MAX_PACKET_SIZE 256 //override value in PubSubClient.h
#define MAX_LINE_LENGTH 1024

byte mac[]    = {  0xDE, 0xED, 0xBA, 0xFE, 0xFE, 0xED };
IPAddress eth_ip     (192,168,1,112); //static IP
IPAddress dns_ip     (192,168,1,20);
IPAddress gateway_ip (192,168,1,20);
IPAddress subnet_mask(255,255,255,0);
EthernetClient ethClient;
PubSubClient client(ethClient);

const char *mqtt_server = "192.168.1.60";
const int  mqttPort = 1883;
const char *clientId = "smartmeters_p1_rw";
const char *topic     = "weigu/basement/storage/smartmeters";
const char *topic_sm1 = "weigu/basement/storage/smartmeter1_p1";
const char *topic_sm2 = "weigu/basement/storage/smartmeter2_p1";
const char *topic_sm3 = "weigu/basement/storage/smartmeter3_p1";
const char *topic_sm4 = "weigu/basement/storage/smartmeter4_p1";
const char *topic_sm5 = "weigu/basement/storage/smartmeter5_p1";
const char *topic_rw  = "weigu/basement/storage/rainwater";

const byte teensy_LED = 13; // PD6 Teensy LED
const byte data_request_SM2 = 2; //active Low!
const byte data_request_SM3 = 3;
const byte data_request_SM4 = 4;
const byte data_request_SM5 = 29;
const byte data_request_SM1 = 30;
const byte data_request_RW6 = 37; //collect data from rainwater sensor
const byte power_LED = 35;
const byte act_LED = 36;

struct TestVector {
    const char *name;
    uint8_t key[16];
    uint8_t ciphertext[MAX_LINE_LENGTH];
    uint8_t authdata[17];
    uint8_t iv[12];
    uint8_t tag[16];
    uint8_t authsize;
    uint16_t datasize;
    uint8_t tagsize;
    uint8_t ivsize; };

TestVector Vector_SM1,Vector_SM2,Vector_SM3,Vector_SM4,Vector_SM5;
GCM<AES128> *gcmaes128 = 0;

//Keys for SAG1030700026xxx
uint8_t key_SM2[] = {0x19, 0xE5, 0xFE, 0x03, 0xC4, 0xB0, 0x65, 0xB4, // Consum.
                     0x25, 0x77, 0xCC, 0x9B, 0xB7, 0x4C, 0x0F, 0x9B};// 430
uint8_t key_SM3[] = {0x5A, 0x9B, 0xDB, 0x8C, 0xE3, 0xFD, 0xB7, 0x02, // PV 10kW
                     0x16, 0x35, 0xFF, 0x6F, 0xB0, 0x2E, 0xE1, 0xDF};// 568
uint8_t key_SM4[] = {0x37, 0xDB, 0x59, 0x3F, 0xBB, 0xDD, 0xE3, 0xC6, // PV 8kW
                     0xA8, 0x28, 0xF3, 0xBF, 0x9A, 0x2E, 0x7F, 0x8B};// 423
uint8_t key_SM5[] = {0x74, 0x5E, 0x2D, 0x96, 0x6E, 0xA0, 0x95, 0xDD, // PV 3kW
                     0x10, 0x46, 0x24, 0xBD, 0x16, 0x6D, 0x6F, 0x2E};// 552

char *identification;
char *p1_version;
char *timestamp;
char *equipment_id;
char *energy_delivered_tariff1;
char *energy_returned_tariff1;
char *reactive_energy_delivered_tariff1;
char *reactive_energy_returned_tariff1;
char *power_delivered;
char *power_returned;
char *reactive_power_delivered;
char *reactive_power_returned;
char *electricity_threshold;
char *electricity_switch_position;
char *electricity_failures;
char *electricity_sags_l1;
char *electricity_sags_l2;
char *electricity_sags_l3;
char *electricity_swells_l1;
char *electricity_swells_l2;
char *electricity_swells_l3;
char *message_short;
char *message2_long;
char *message3_long;
char *message4_long;
char *message5_long;
char *current_l1;
char *current_l2;
char *current_l3;

char *id_p1_version = "1-3:0.2.8(";
char *id_timestamp = "0-0:1.0.0(";
char *id_equipment_id = "0-0:42.0.0(";
char *id_energy_delivered_tariff1 = "1-0:1.8.0(";
char *id_energy_returned_tariff1 = "1-0:2.8.0(";
char *id_reactive_energy_delivered_tariff1 = "1-0:3.8.0(";
char *id_reactive_energy_returned_tariff1 = "1-0:4.8.0(";
char *id_power_delivered = "1-0:1.7.0(";
char *id_power_returned = "1-0:2.7.0(";
char *id_reactive_power_delivered = "1-0:3.7.0(";
char *id_reactive_power_returned = "1-0:4.7.0(";
char *id_electricity_threshold = "0-0:17.0.0(";
char *id_electricity_switch_position = "0-0:96.3.10(";
char *id_electricity_failures = "0-0:96.7.21(";
char *id_electricity_sags_l1 = "1-0:32.32.0(";
char *id_electricity_sags_l2 = "1-0:52.32.0(";
char *id_electricity_sags_l3 = "1-0:72.32.0(";
char *id_electricity_swells_l1 = "1-0:32.36.0(";
char *id_electricity_swells_l2 = "1-0:52.36.0(";
char *id_electricity_swells_l3 = "1-0:72.36.0(";
char *id_message_short = "0-0:96.13.0(";
char *id_message2_long = "0-0:96.13.2(";
char *id_message3_long = "0-0:96.13.3(";
char *id_message4_long = "0-0:96.13.4(";
char *id_message5_long = "0-0:96.13.5(";
char *id_current_l1 = "1-0:31.7.0(";
char *id_current_l2 = "1-0:51.7.0(";
char *id_current_l3 = "1-0:71.7.0(";

const char filename2[13] = "10_04_18.txt";
uint8_t telegram[MAX_LINE_LENGTH];
char rainwater[6] = "E999\n";
char buffer[MAX_LINE_LENGTH-30];

const byte CS_ETH_pin = 24; // MOSI0 11 MISO0 12
const byte SCK_ETH_pin = 14;
const byte CS_SD = BUILTIN_SDCARD;

char msg[MQTT_MAX_PACKET_SIZE];
char msg_sm1[MQTT_MAX_PACKET_SIZE], msg_sm2[MQTT_MAX_PACKET_SIZE];
char msg_sm3[MQTT_MAX_PACKET_SIZE], msg_sm4[MQTT_MAX_PACKET_SIZE];
char msg_sm5[MQTT_MAX_PACKET_SIZE], msg_rw[128], SDline[1024], filename[13];

byte tsec, tmin, thour, tweekd, tday, tmon, tyear;
int test,Tlength;

void setup() {
  delay(10000); //time to connect 2 smartmeter (needs more than 250mA!)

  pinMode(teensy_LED, OUTPUT);    // Initialize outputs
  pinMode(data_request_SM1, OUTPUT);
  pinMode(data_request_SM2, OUTPUT);
  pinMode(data_request_SM3, OUTPUT);
  pinMode(data_request_SM4, OUTPUT);
  pinMode(data_request_SM5, OUTPUT);
  pinMode(data_request_RW6, OUTPUT);
  pinMode(data_request_RW6, OUTPUT);
  pinMode(power_LED, OUTPUT);
  pinMode(act_LED, OUTPUT);
  digitalWrite(power_LED,HIGH);   // On
  digitalWrite(teensy_LED,HIGH);   // On

  setSyncProvider(getTeensy3Time); // set the Time lib for Teensy 3 RTC

  SPI.setSCK(SCK_ETH_pin);

  digitalWrite(teensy_LED,HIGH);   // On
  Serial.begin(115200);  // for debugging
  Serial.println("Serial is working!");

  Serial1.begin(115200);
  Serial2.begin(115200);
  Serial3.begin(115200);
  Serial4.begin(115200);
  Serial5.begin(115200);
  Serial6.begin(9600); //rainwater sensor XL-MaxSonar MB7060

  Serial.print("Initializing SD card...");
  if (!SD.begin(CS_SD)) { // see if the card is present and can be initialized:
    Serial.println("Card failed, or not present");
    return; }
  Serial.println("card initialized.");

  client.setServer(mqtt_server,mqttPort);
  Ethernet.init(CS_ETH_pin); //needed to avoid conflict with SD card!!
  Ethernet.begin(mac, eth_ip);
  delay(1500);  // Allow the hardware to sort itself out
  digitalWrite(teensy_LED,LOW);   // Off, less energy
  }

void loop() {
  if (second()==0) {
    digitalWrite(act_LED,HIGH);   // On
    digitalClockDisplay();

    if (!client.connected()) { reconnect(); }
    client.loop();
    Serial.println("Loop beginns");

    //Rainwater first
    digitalWrite(data_request_RW6,HIGH);   // Request serial data On
    delay(20);
    Tlength = readTelegram(6);
    digitalWrite(data_request_RW6,LOW);  // Request serial data Off
    snprintf (msg, 40, "{\"rainwater\":\"distance\",\"cm\":\"%c%c%c\"}",
              rainwater[1],rainwater[2],rainwater[3]);    
    snprintf (msg_rw, 40, "%c%c%c",rainwater[1],rainwater[2],rainwater[3]);              
    Serial.println(msg);
    Serial.println(msg_rw);
    test=client.publish(topic_rw, msg);
    
    //SM2 on Serial1
    memset(telegram, '1', sizeof(telegram));
    digitalWrite(data_request_SM2,LOW);   // Request serial data On
    delay(10);
    Tlength = readTelegram(1);
    digitalWrite(data_request_SM2,HIGH);   // Request serial data Off
    Serial.print("Message length: ");
    Serial.println(Tlength);
    init_vector(&Vector_SM2,"Vector_SM2",key_SM2);
    if (Vector_SM2.datasize != 1024) {
      decrypt_text(&Vector_SM2);
      parse_dsmr_string(buffer);
      snprintf (msg, MQTT_MAX_PACKET_SIZE, "{\"dt\":\"%s\",\"id\":\"%c%c%c\""
                ",\"c1\":\"%s\",\"p1\":\"%s\",\"c2\":\"%s\",\"p2\":\"%s\"}",
                timestamp,equipment_id[13],equipment_id[14],equipment_id[15],
                energy_delivered_tariff1, energy_returned_tariff1,
                reactive_energy_delivered_tariff1,
                reactive_energy_returned_tariff1);
      snprintf (msg_sm2, 128, "%c%c%c\t%s\t%s\t%s\t%s\t%s",
                equipment_id[13],equipment_id[14],equipment_id[15],timestamp,
                energy_delivered_tariff1, energy_returned_tariff1,
                reactive_energy_delivered_tariff1,
                reactive_energy_returned_tariff1);
      Serial.println(msg);
      Serial.println(msg_sm2);
      test=client.publish(topic_sm2, msg);
    }

    //SM3 on Serial2
    memset(telegram, '1', sizeof(telegram));
    digitalWrite(data_request_SM3,LOW);   // Request serial data On
    delay(10);
    Tlength = readTelegram(2);
    digitalWrite(data_request_SM3,HIGH);   // Request serial data Off
    Serial.print("Message length: ");
    Serial.println(Tlength);
    init_vector(&Vector_SM3,"Vector_SM3",key_SM3);
    if (Vector_SM3.datasize != 1024) {
      decrypt_text(&Vector_SM3);
      parse_dsmr_string(buffer);
      snprintf (msg, MQTT_MAX_PACKET_SIZE, "{\"dt\":\"%s\",\"id\":\"%c%c%c\""
                ",\"c1\":\"%s\",\"p1\":\"%s\",\"c2\":\"%s\",\"p2\":\"%s\"}",
                timestamp,equipment_id[13],equipment_id[14],equipment_id[15],
                energy_delivered_tariff1, energy_returned_tariff1,
                reactive_energy_delivered_tariff1,
                reactive_energy_returned_tariff1);
      snprintf (msg_sm3, 128, "%c%c%c\t%s\t%s\t%s\t%s\t%s",
                equipment_id[13],equipment_id[14],equipment_id[15],timestamp,
                energy_delivered_tariff1, energy_returned_tariff1,
                reactive_energy_delivered_tariff1,
                reactive_energy_returned_tariff1);
      Serial.println(msg);
      Serial.println(msg_sm3);
      test=client.publish(topic_sm3, msg);
    }

    //SM4 on Serial3
    memset(telegram, '1', sizeof(telegram));
    digitalWrite(data_request_SM4,LOW);   // Request serial data On
    delay(10);
    Tlength = readTelegram(3);
    digitalWrite(data_request_SM4,HIGH);   // Request serial data Off
    Serial.print("Message length: ");
    Serial.println(Tlength);
    init_vector(&Vector_SM4,"Vector_SM4",key_SM4);
    if (Vector_SM4.datasize != 1024) {
      decrypt_text(&Vector_SM4);
      parse_dsmr_string(buffer);
      snprintf (msg, MQTT_MAX_PACKET_SIZE, "{\"dt\":\"%s\",\"id\":\"%c%c%c\""
                ",\"c1\":\"%s\",\"p1\":\"%s\",\"c2\":\"%s\",\"p2\":\"%s\"}",
                timestamp,equipment_id[13],equipment_id[14],equipment_id[15],
                energy_delivered_tariff1, energy_returned_tariff1,
                reactive_energy_delivered_tariff1,
                reactive_energy_returned_tariff1);
      snprintf (msg_sm4, 128, "%c%c%c\t%s\t%s\t%s\t%s\t%s",
                equipment_id[13],equipment_id[14],equipment_id[15],timestamp,
                energy_delivered_tariff1, energy_returned_tariff1,
                reactive_energy_delivered_tariff1,
                reactive_energy_returned_tariff1);
      Serial.println(msg);
      Serial.println(msg_sm4);
      test=client.publish(topic_sm4, msg);
    }

    //SM5 on Serial4
    memset(telegram, '1', sizeof(telegram));
    digitalWrite(data_request_SM5,LOW);   // Request serial data On
    delay(10);
    Tlength = readTelegram(4);
    digitalWrite(data_request_SM5,HIGH);   // Request serial data Off
    Serial.print("Message length: ");
    Serial.println(Tlength);
    /*Serial.print("T: ");
    for(int cnt=0; cnt<10;cnt++)
          Serial.print(telegram[cnt],HEX);
    Serial.println();  */
    init_vector(&Vector_SM5,"Vector_SM5",key_SM5);
    //print_vector(&Vector_SM5);
    if (Vector_SM5.datasize != 1024) {
      decrypt_text(&Vector_SM5);
      parse_dsmr_string(buffer);
      //print_dsmr();
      snprintf (msg, MQTT_MAX_PACKET_SIZE, "{\"dt\":\"%s\",\"id\":\"%c%c%c\""
                ",\"c1\":\"%s\",\"p1\":\"%s\",\"c2\":\"%s\",\"p2\":\"%s\"}",
                timestamp,equipment_id[13],equipment_id[14],equipment_id[15],
                energy_delivered_tariff1, energy_returned_tariff1,
                reactive_energy_delivered_tariff1,
                reactive_energy_returned_tariff1);
      snprintf (msg_sm5, 128, "%c%c%c\t%s\t%s\t%s\t%s\t%s",
                equipment_id[13],equipment_id[14],equipment_id[15],timestamp,
                energy_delivered_tariff1, energy_returned_tariff1,
                reactive_energy_delivered_tariff1,
                reactive_energy_returned_tariff1);
      Serial.println(msg);
      Serial.println(msg_sm5);
      test=client.publish(topic_sm5, msg);
    }

    //get_time(&tsec, &tmin, &thour, &tweekd, &tday, &tmon, &tyear);//if DS3231
    snprintf (filename, 13, "%02d_%02d_%02d.txt",day(), month(), year()-2000);
    Serial.println(filename);

    File dataFile = SD.open(filename, FILE_WRITE); // open file
    if (dataFile) {  // if the file is available, write to it:
      snprintf (SDline, 1024, "%s\t%s\t%s\t%s\t%s\n",
                msg_sm2, msg_sm3, msg_sm4, msg_sm5, msg_rw);
      dataFile.println(SDline);
      dataFile.close(); }
    else {
      Serial.println("error opening file.txt");}
    Serial.println("published");  
    delay(1000);
    digitalWrite(act_LED,LOW);   // Off
  }
}


int readTelegram(int nr) {
  int cnt = 0;
  switch (nr) {
    case 1:
      while ((Serial1.available()) && (cnt!= MAX_LINE_LENGTH)) {
        telegram[cnt] = Serial1.read();
        cnt++; }
      break;
    case 2:
      while ((Serial2.available()) && (cnt!= MAX_LINE_LENGTH)) {
        telegram[cnt] = Serial2.read();
        cnt++; }
      break;
    case 3:
      while ((Serial3.available()) && (cnt!= MAX_LINE_LENGTH)) {
        telegram[cnt] = Serial3.read();
        cnt++; }
      break;
    case 4:
      while ((Serial4.available()) && (cnt!= MAX_LINE_LENGTH)) {
        telegram[cnt] = Serial4.read();
        cnt++; }
      break;
    case 5:
      while ((Serial5.available()) && (cnt!= MAX_LINE_LENGTH)) {
        telegram[cnt] = Serial5.read();
        cnt++; }
      break;
    case 6:
      while ((Serial6.available()) && (cnt!= 5)) {
        rainwater[cnt] = Serial6.read();
        cnt++; }
      break;
    default:
      Serial.println("no such serial port");
      break; }
  return (cnt); }

void reconnect() {
  while (!client.connected()) { // Loop until we're reconnected
    if (client.connect(clientId)) { // Attempt to connect publish announcement
      client.publish(topic, "{\"smartmeters_P1\":\"connected\"}"); }
    else { delay(5000); }}}// Wait 5 seconds before retrying

// Convert binary coded decimal to decimal number
byte bcdToDec(byte val) { return((val/16*10) + (val%16)); }

// Convert decimal number to binary coded decimal
byte decToBcd(byte val) { return((val/10*16) + (val%10)); }





time_t getTeensy3Time() { return Teensy3Clock.get(); }

void digitalClockDisplay() {
  // digital clock display of the time
  Serial.print(hour());
  printDigits(minute());
  printDigits(second());
  Serial.print(" ");
  Serial.print(day());
  Serial.print(" ");
  Serial.print(month());
  Serial.print(" ");
  Serial.print(year());
  Serial.println(); }

void printDigits(int digits){
  // utility function clock display: prints preceding colon and leading 0
  Serial.print(":");
  if(digits < 10)
    Serial.print('0');
  Serial.print(digits); }

  void init_vector(TestVector *vect, char *Vect_name, uint8_t *key_SM) {
    uint16_t Data_Length;
    vect->name = Vect_name;  // vector name
    for (int i = 0; i < 16; i++)
       vect->key[i] = key_SM[i];
    // get length of data
    Data_Length = uint16_t(telegram[11])*256 + uint16_t(telegram[12])-17;
    if (Data_Length>MAX_LINE_LENGTH) Data_Length = MAX_LINE_LENGTH;
    for (int i = 0; i < Data_Length; i++)
       vect->ciphertext[i] = telegram[i+18];
    uint8_t AuthData[] = {0x30, 0x00, 0x11, 0x22, 0x33, 0x44, 0x55, 0x66,
                          0x77, 0x88, 0x99, 0xAA, 0xBB, 0xCC, 0xDD, 0xEE,
                          0xFF};
    for (int i = 0; i < 17; i++)
       vect->authdata[i] = AuthData[i];
    for (int i = 0; i < 8; i++)
       vect->iv[i] = telegram[2+i];
    for (int i = 8; i < 12; i++)
       vect->iv[i] = telegram[6+i];
    for (int i = 0; i < 12; i++)
       vect->tag[i] = telegram[Data_Length+18+i];
    vect->authsize = 17;
    vect->datasize = Data_Length;
    vect->tagsize = 12;
    vect->ivsize  = 12; }

void decrypt_text(TestVector *vect) {
  gcmaes128 = new GCM<AES128>();
  size_t posn, len;
  size_t inc = vect->datasize;
  memset(buffer, 0xBA, sizeof(buffer));
  gcmaes128->setKey(vect->key, gcmaes128->keySize());
  gcmaes128->setIV(vect->iv, vect->ivsize);
  for (posn = 0; posn < vect->datasize; posn += inc) {
    len = vect->datasize - posn;
    if (len > inc) len = inc;
    gcmaes128->decrypt((uint8_t*)buffer + posn, vect->ciphertext + posn, len);
   }
  delete gcmaes128;
  /*for (int i = 0; i < vect->datasize; i++)
    Serial.print(buffer[i]);*/
}

void parse_dsmr_string(char *mystring) {
   bool result;
   char *field;
   identification = strtok(mystring, "\n"); // get the first field
   while ((field[0] != '!') && (field != NULL)) { // walk through other fields
     field = strtok(NULL, "\n");
     result=test_field(field,id_p1_version);
     if (result) {
        get_field(field);
        p1_version = field;
      }
     result=test_field(field,id_timestamp);
     if (result) {
        get_field(field);
        timestamp = field;
      }
     result=test_field(field,id_equipment_id);
     if (result) {
        get_field(field);
        convert_equipment_id(field);
        equipment_id = field;
      }
     result=test_field(field,id_energy_delivered_tariff1);
     if (result) {
        get_field(field);
        energy_delivered_tariff1 = field;
      }
     result=test_field(field,id_energy_returned_tariff1);
     if (result) {
        get_field(field);
        energy_returned_tariff1 = field;
      }
     result=test_field(field,id_reactive_energy_delivered_tariff1);
     if (result) {
        get_field(field);
        reactive_energy_delivered_tariff1 = field;
      }
     result=test_field(field,id_reactive_energy_returned_tariff1);
     if (result) {
        get_field(field);
        reactive_energy_returned_tariff1 = field;
      }
     result=test_field(field,id_power_delivered);
     if (result) {
        get_field(field);
        power_delivered = field;
      }
     result=test_field(field,id_power_returned);
     if (result) {
        get_field(field);
        power_returned = field;
      }
     result=test_field(field,id_reactive_power_delivered);
     if (result) {
        get_field(field);
        reactive_power_delivered = field;
      }
     result=test_field(field,id_reactive_power_returned);
     if (result) {
        get_field(field);
        reactive_power_returned = field;
      }
     result=test_field(field,id_electricity_threshold);
     if (result) {
        get_field(field);
        electricity_threshold = field;
      }
     result=test_field(field,id_electricity_switch_position);
     if (result) {
        get_field(field);
        electricity_switch_position = field;
      }
     result=test_field(field,id_electricity_failures);
     if (result) {
        get_field(field);
        electricity_failures = field;
      }
     result=test_field(field,id_electricity_sags_l1);
     if (result) {
        get_field(field);
        electricity_sags_l1 = field;
      }
     result=test_field(field,id_electricity_sags_l2);
     if (result) {
        get_field(field);
        electricity_sags_l2 = field;
      }
     result=test_field(field,id_electricity_sags_l3);
     if (result) {
        get_field(field);
        electricity_sags_l3 = field;
      }
     result=test_field(field,id_electricity_swells_l1);
     if (result) {
        get_field(field);
        electricity_swells_l1 = field;
      }
     result=test_field(field,id_electricity_swells_l2);
     if (result) {
        get_field(field);
        electricity_swells_l2 = field;
      }
     result=test_field(field,id_electricity_swells_l3);
     if (result) {
        get_field(field);
        electricity_swells_l3 = field;
      }
     result=test_field(field,id_message_short);
     if (result) {
        get_field(field);
        message_short = field;
      }
     result=test_field(field,id_message2_long);
     if (result) {
        get_field(field);
        message2_long = field;
      }
     result=test_field(field,id_message3_long);
     if (result) {
        get_field(field);
        message3_long = field;
      }
     result=test_field(field,id_message4_long);
     if (result) {
        get_field(field);
        message4_long = field;
      }
     result=test_field(field,id_message5_long);
     if (result) {
        get_field(field);
        message5_long = field;
      }
     result=test_field(field,id_current_l1);
     if (result) {
        get_field(field);
        current_l1 = field;
      }
     result=test_field(field,id_current_l2);
     if (result) {
        get_field(field);
        current_l2 = field;
      }
     result=test_field(field,id_current_l3);
     if (result) {
        get_field(field);
        current_l3 = field;
      }
   }
}

void convert_equipment_id(char *mystring) { //coded in HEX
  int len =strlen(mystring);
  for (int i=0; i<len/2; i++)
    mystring[i]=char(((int(mystring[i*2]))-48)*16+(int(mystring[i*2+1])-48));
  mystring[(len/2)]= NULL;
}
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

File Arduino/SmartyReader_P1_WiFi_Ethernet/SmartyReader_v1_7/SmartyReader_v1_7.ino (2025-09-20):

/*
  SmartyReader_1_7.ino

  Read P1 port from Luxemburgian smartmeter.
  Decode and publish with MQTT over Wifi or Ethernet
  using ESP8266 (LOLIN/WEMOS D1 mini pro) or ESP32 (MH ET LIVE ESP32MiniKit)
  ESP8266 is recommended (more stable)

  V0.1 2017-08-16
  V1.0 2019-05-04
  V1.1 2019-05-05 OTA added
  V1.2 2019-12-09 now using my new helper lib: ESPBacker
  V1.3 2020-06-23 major changes in code, working with with Strings, publish
                  all data (json or string)
  V1.4 2020-06-24 enable line no more switched (10s data)
  V1.5 2021-04-26 for new boards V2.0 (PCB) without transistor
                  old hardware supported
  V1.6 2022-07-16 Using config or secrets file for password, 3 new gas fields,
                  BME280 suppport, changed ESPBacker to ESPToolbox,
                  added Ethernet, bugfixes
  V1.7 2025-04-30 Added calculated values for exceeding power classes
                  Added discovery function Home Assistant (Markus Schöllauf)
                  MQTT will and birth (Jean-Marie Quintus)
       2025-05-28 Added money calculation for exceeding power
  ---------------------------------------------------------------------------
  Copyright (C) 2017 Guy WEILER www.weigu.lu

  With ideas from Sam Grimee, Bob Fisch (www.fisch.lu), and Serge Wagner
  Alternative Software: https://githuTb.com/sgrimee

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
  This program is distributed in the hope that it will be useful,
  but WITHOUT ANY WARRANTY; without even the implied warranty of
  MERCHANTABILITY or FITNESS FOR A PARTICULAR PURPOSE.  See the
  GNU General Public License for more details.
  You should have received a copy of the GNU General Public License
  along with this program.  If not, see <https://www.gnu.org/licenses/>.
  ---------------------------------------------------------------------------

  More information on AES128-GCM can be found on:
  http://weigu.lu/tutorials/sensors2bus/04_encryption/index.html.
  More information on MQTT can be found on:
  http://weigu.lu/tutorials/sensors2bus/06_mqtt/index.html.

  Data from Smarty are on Serial (Serial0) RxD on ESP.
  If you want to debug over Serial, use Serial1 for LOLIN/WEMOS D1 mini pro:
  Transmit-only UART TxD on D4 (LED!)
  For MHEtLive ESP32MiniKit use Serial1 TxD or Serial2 TxD

  If using OTA (not MQTTSECURE!):
  Port defaults to 8266,  Hostname defaults to esp3232-[MAC],
  We set the password here with it's md5 value
  To get md5 on Ubuntu use "md5sum": md5sum, enter, type pw, 2x Ctrl D

  Hardware serial (Serial) on LOLIN/WEMOS D1 mini pro uses UART0 of ESP8266,
  which is mapped to pins TX (GPIO1) and RX (GPIO3). It is used to access the
  smartmeter.

  !! You have to remove the LOLIN/WEMOS from its socket to program it! because the
  hardware serial port is also used during programming !!

  Serial1 uses UART1 which is a transmit-only UART. UART1 TX pin is D4 (GPIO2,
  LED!!). If you use serial (UART0) to communicate with hardware, you can't use
  the Arduino Serial Monitor at the same time to debug your program! The best
  way to debug is to use Serial1.println() and connect RX of an USB2Serial
  adapter (FTDI, Profilic, CP210, ch340/341) to D4 and use a terminal program
  like CuteCom or CleverTerm to listen to D4.

  Another possibility to debug is to use UDP.
  You can listen on Linux PC (UDP_LOG_PC_IP) with netcat command: nc -kulw 0 6666

  You can also use an MH ET LIVE ESP32MiniKit board. Add a capacitor
  1000µF,10V (better 4700µF,10V) to the 5V header (look on weigu.lu)

  ESP8266: LOLIN/WEMOS D1 mini pro
  ESP32:   MH ET LIVE ESP32-MINI-KIT

  MHET    | MHET    - LOLIN        |---| LOLIN      - MHET    | MHET

  GND     | RST     - RST          |---| TxD        - RxD(3)  | GND
   NC     | SVP(36) -  A0          |---| RxD        - TxD(1)  | 27
  SVN(39) | 26      -  D0(16)      |---|  D1(5,SCL) -  22     | 25
   35     | 18      -  D5(14,SCK)  |---|  D2(4,SDA) -  21     | 32
   33     | 19      -  D6(12,MISO) |---|  D3(0)     -  17     | TDI(12)
   34     | 23      -  D7(13,MOSI) |---|  D4(2,LED) -  16     | 4
  TMS(14) | 5       -  D8(15,SS)   |---| GND        - GND     | 0
   NC     | 3V3     - 3V3          |---|  5V        -  5V     | 2
  SD2(9)  | TCK(13)                |---|              TD0(15) | SD1(8)
  CMD(11) | SD3(10)                |---|              SD0(7)  | CLK(6)

  We need a the following libraries:

  + `Crypto` (Rhys Wheatherley)
  + `PubSubClient`  (by Nick O'Leary)
  + `ArduinoJson` (Benoit Blanchon)
  + `circular Buffer` (AgileWare, Roberto Lo Giacco)
  + `BME280` (Tyler Glenn); only if you use a BME280! 

*/

/*!!!!!!!!!! make your changes in config.h (or secrets.h) !!!!!!!!!*/

/*!!!!!!!!!! to debug you can use the onboard LED, a second serial port on D4
             or best: UDP! Look in setup()                !!!!!!!!!*/
             
/*?????? Comment or uncomment the following lines suiting your needs ??????*/

/* The file "secrets_xxx.h" has to be placed in the sketchbook libraries folder
   in a folder named "Secrets" and must contain the same things than the file config.h*/
#define MY_SECRETS_FILE <secrets_smartmeter_main.h>
//#define USE_SECRETS
//#define OTA                // if Over The Air update needed (security risk!)
//#define MQTTPASSWORD       // if you want an MQTT connection with password (recommended!!)
//#define MQTT_WILL_BIRTH    // if you want an MQTT will
//#define STATIC             // if static IP needed (no DHCP)
//#define ETHERNET           // if Ethernet (W5500) instead of WiFi
//#define BME280_I2C         // if you want to add a temp sensor to I2C connector
#define GET_NTP_TIME       // if you need the real time
/* everything item (DSMR and calculated) is normally published under its own topic
 * in config.h (or secrets.h) you can decide with 'y/n' if you want to publish it
 * PUBLISH_COOKED is a JSON String with the calculated values (needed by me :))*/
#define PUBLISH_COOKED
//!!! memory problems MQTT? with HOMEASSISTANT
//#define HOMEASSISTANT      // add dicovery function for Home Assistant
//------------------------
//#define OLD_HARDWARE      // for the boards before V2.0
//#define FUNDUINO_W5100    // for the boards before V2.2 if using Ethernet
                            // (W5100 instead W5500)


/****** Arduino libraries needed ******/
#ifdef USE_SECRETS
  #include MY_SECRETS_FILE
#else  
  #include "config.h"      // most of the things you need to change are here
#endif // USE_SECRETS  
#include "ESPToolbox.h"  // ESP helper lib (more on weigu.lu)
#include <PubSubClient.h>
#include <ArduinoJson.h>
#include <CircularBuffer.h>
#include <Crypto.h>
#include <AES.h>
#include <GCM.h>
#include <math.h>
//#include <time.h>
#ifdef BME280_I2C
  #include <Wire.h>
  #include <BME280I2C.h>
#endif
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

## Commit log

2021-05-03 added PUBLISH_ALL switch
2022-02-18 corrected links
    [smartyreader_ng_lora-B_Adhes.gbr, smartyreader_ng_lora-B_CrtYd.gbr, smartyreader_ng_lora-B_Cu.gbr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]
2022-02-18 Changed image and KiCAD files to V2.1
    [smartmeter_P1_board-2019-03-23-15-43-31.sch, smartmeter_P1_board-2019-08-18-11-39-25.sch, smartmeter_P1_board-2019-12-31-16-50-38.sch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]
2022-03-14 added FreeCAD and stl files
    [SmartyReader_P1_WiFi.FCStd, SmartyReader_P1_WiFi_Lid.stl, SmartyReader_P1_WiFi_case_bottom.stl]
2022-03-17 enhanced housing with notch
    [SmartyReader_P1_WiFi.FCStd, SmartyReader_P1_WiFi_Lid.stl, SmartyReader_P1_WiFi_case_bottom.stl]
2022-04-18 adding calculation of excess power
2022-05-17 changed README in /Arduino/SmartyReader_P1_WiFi/
2022-06-07 bug in config file, and more infos in the software README
    [SmartyReader_v1_6_beta.ino]
2022-06-12 addes constrain to excess power (no more negative)
2022-10-05 corrected missing fillet
    [SmartyReader_P1_WiFi-Case.stl, SmartyReader_P1_WiFi.FCStd, SmartyReader_P1_WiFi_case_bottom.stl]
2022-10-15 readded P1 version; corrected kWh to Wh (calc) and added gas_cumul_day
    [SmartyReader_v1_6.ino]
2022-11-19 Support for W5500 Ethernet board (v2.2); KiCAD files (v2.2)
    [smartyreader-2019-04-01-10-52-08.sch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]
2023-03-31 set enable pin OLD_HARDWARE only in setup()
2025-05-06 bug, production instead consumption
    [SmartyReader_v1_7.ino]
2025-05-06 bug, production instead consumption, new last will
    [SmartyReader_v1_7.ino]
2025-05-08 power_from_energy calculated over 1 Minute for better resolution

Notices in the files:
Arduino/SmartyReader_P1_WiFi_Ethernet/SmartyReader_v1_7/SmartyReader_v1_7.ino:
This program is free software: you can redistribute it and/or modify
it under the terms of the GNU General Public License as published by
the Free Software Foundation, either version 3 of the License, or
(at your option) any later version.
